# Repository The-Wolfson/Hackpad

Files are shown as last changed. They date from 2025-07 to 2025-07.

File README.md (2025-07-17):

# MIDI (Pro) Pad
A hackpad built for [Hacklub's YSWS](hackpad.hackclub.com) that sends MIDI Control Messages to your DAW of choice. It features 2 rotary encoders, 9 switches, and 16 addressable LEDs.

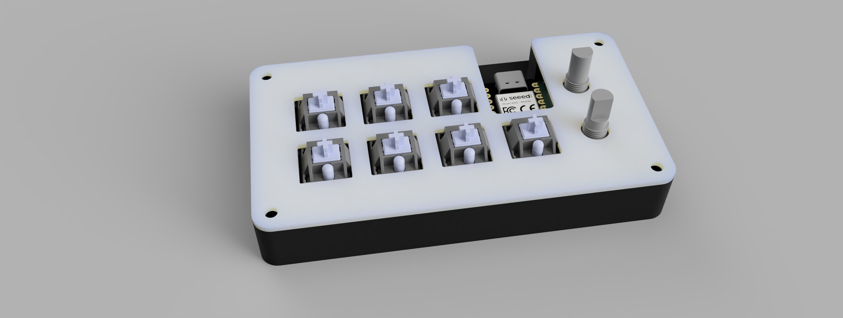
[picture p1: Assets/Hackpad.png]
Assembled

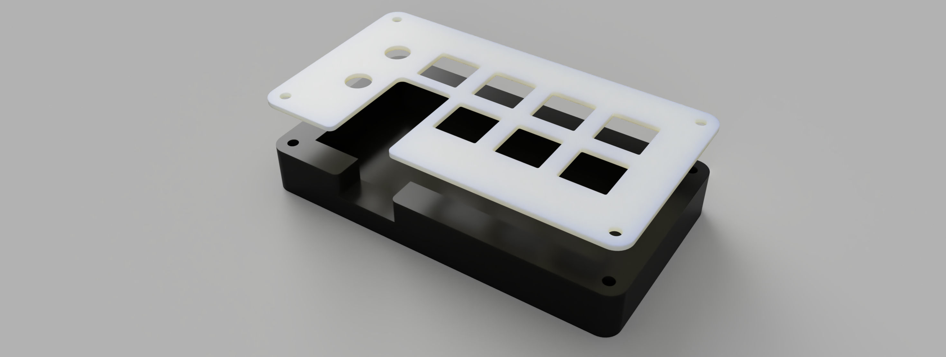
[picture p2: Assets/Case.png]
Case

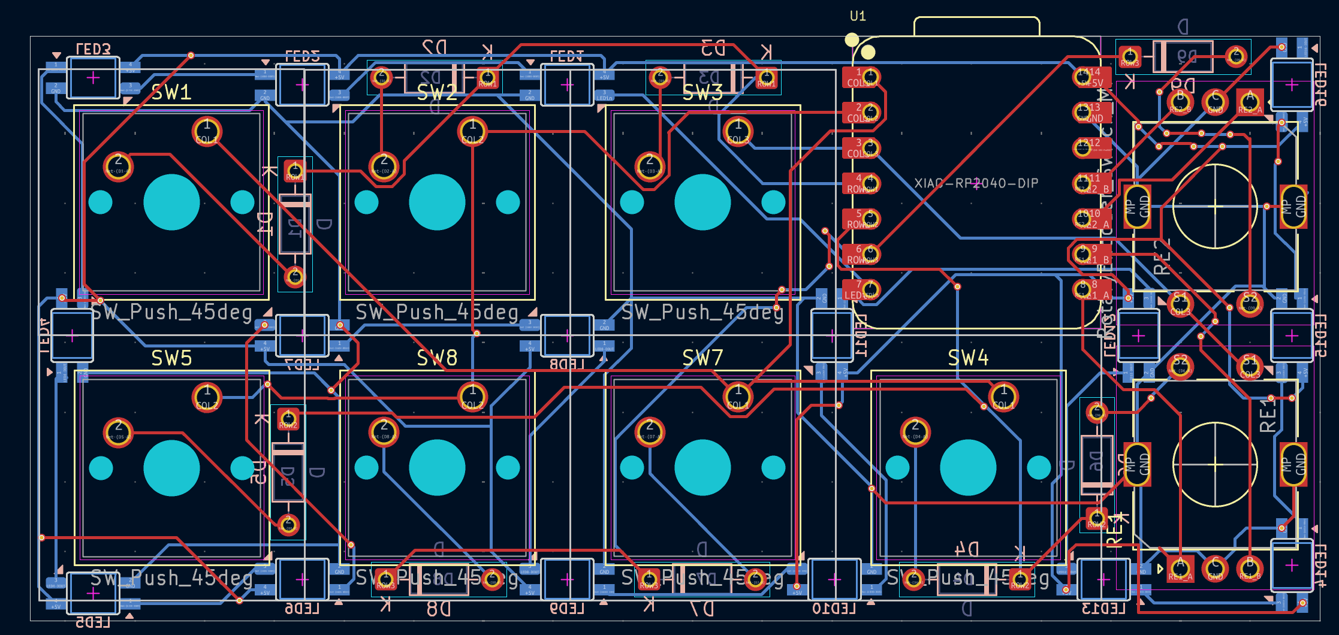
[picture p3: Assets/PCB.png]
PCB

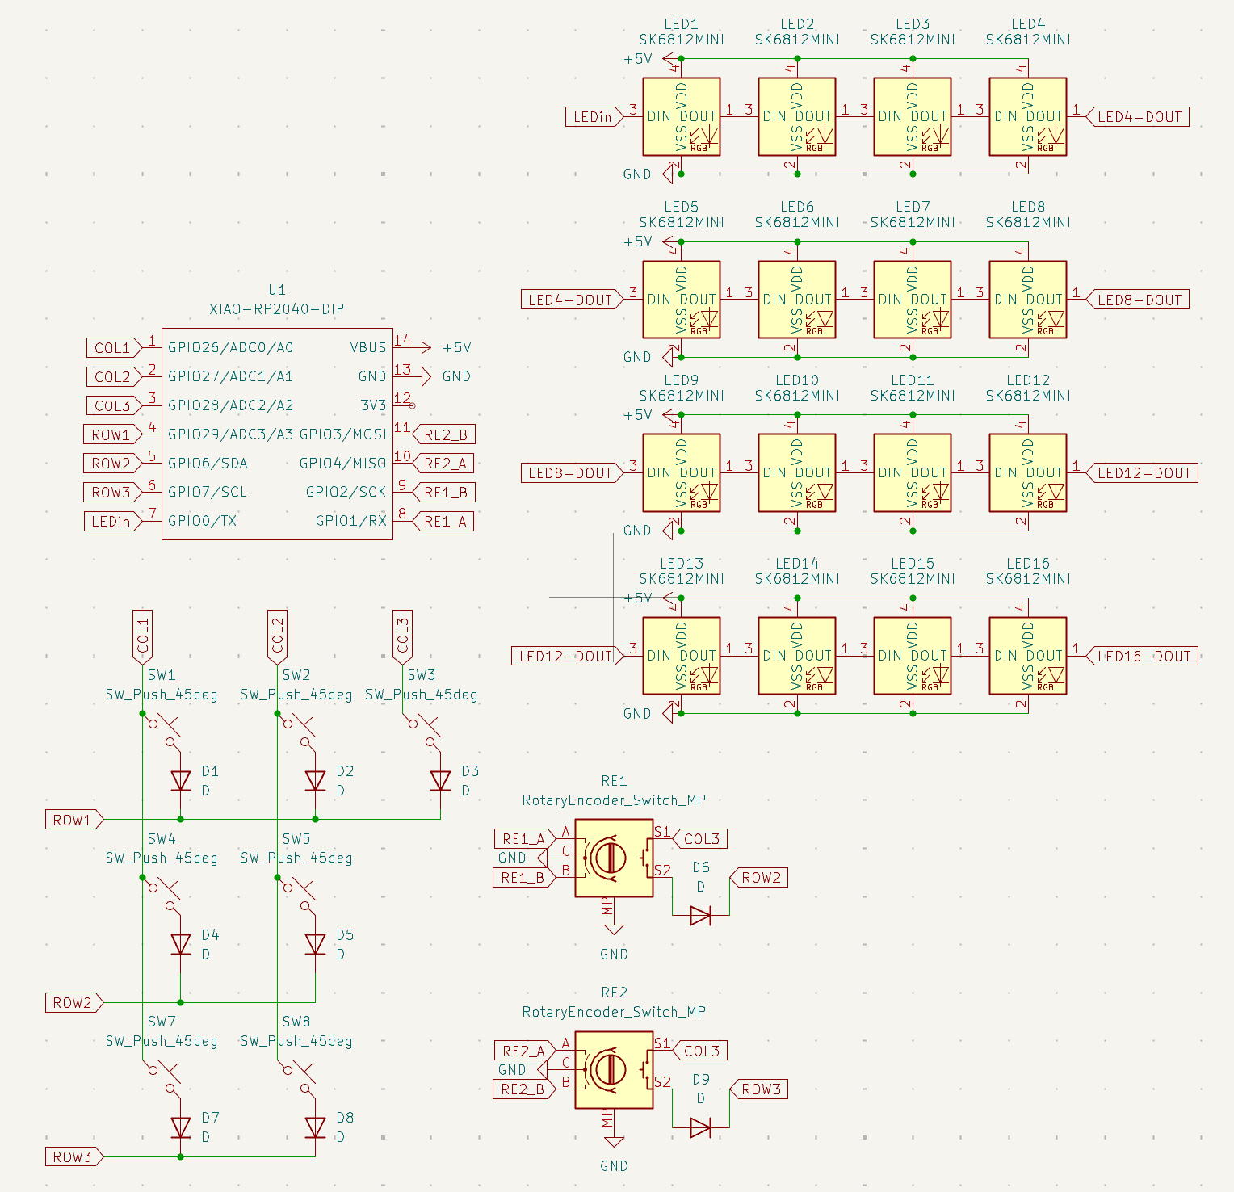
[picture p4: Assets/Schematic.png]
Schematic


## BOM
| Part | Quantity |
| - | - |
| XIAO RP2040 | 1 |
| EC11 Rotary Encoder | 2 |
| SK6812 MINI-E | 16 |
| MX-Style Switch | 7|
| Through-hole 1N4148 Diode | 9 |
| M3x16mm Screw | 4 |
| M3x5mx4mm Heatset Insert | 4 |

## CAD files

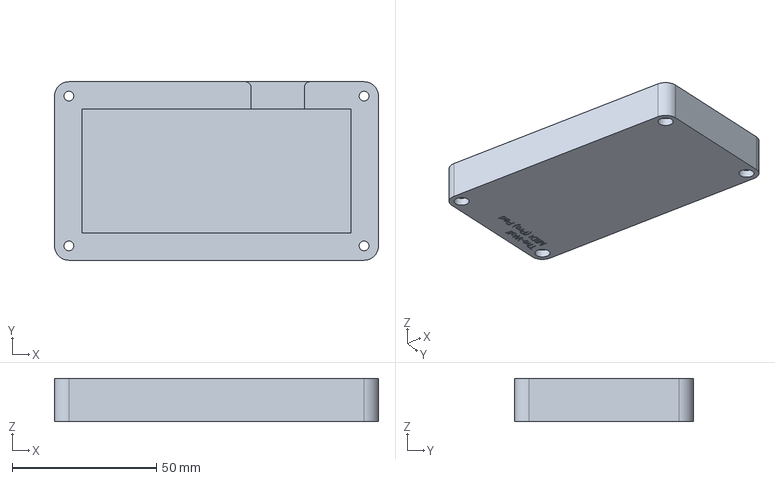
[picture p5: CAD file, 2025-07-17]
Production/Bottom.step
112.5 x 62.0 x 15.0 mm

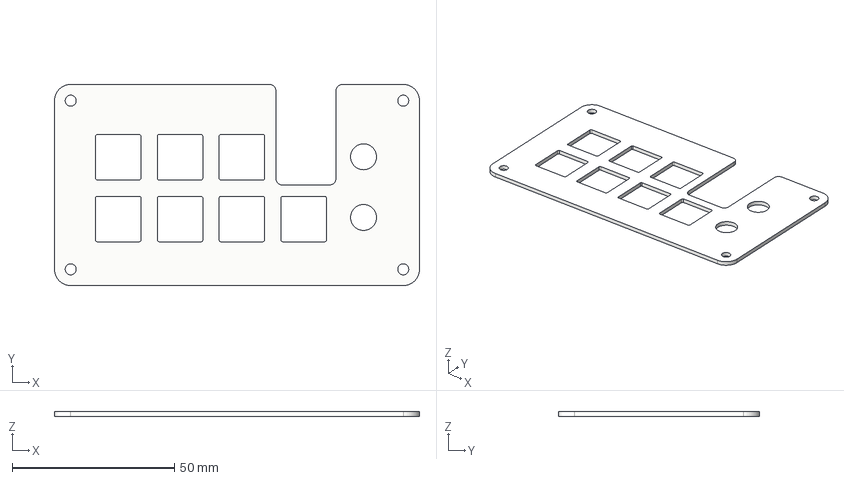
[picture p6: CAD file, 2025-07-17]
Production/Top.step
112.5 x 62.0 x 1.50 mm

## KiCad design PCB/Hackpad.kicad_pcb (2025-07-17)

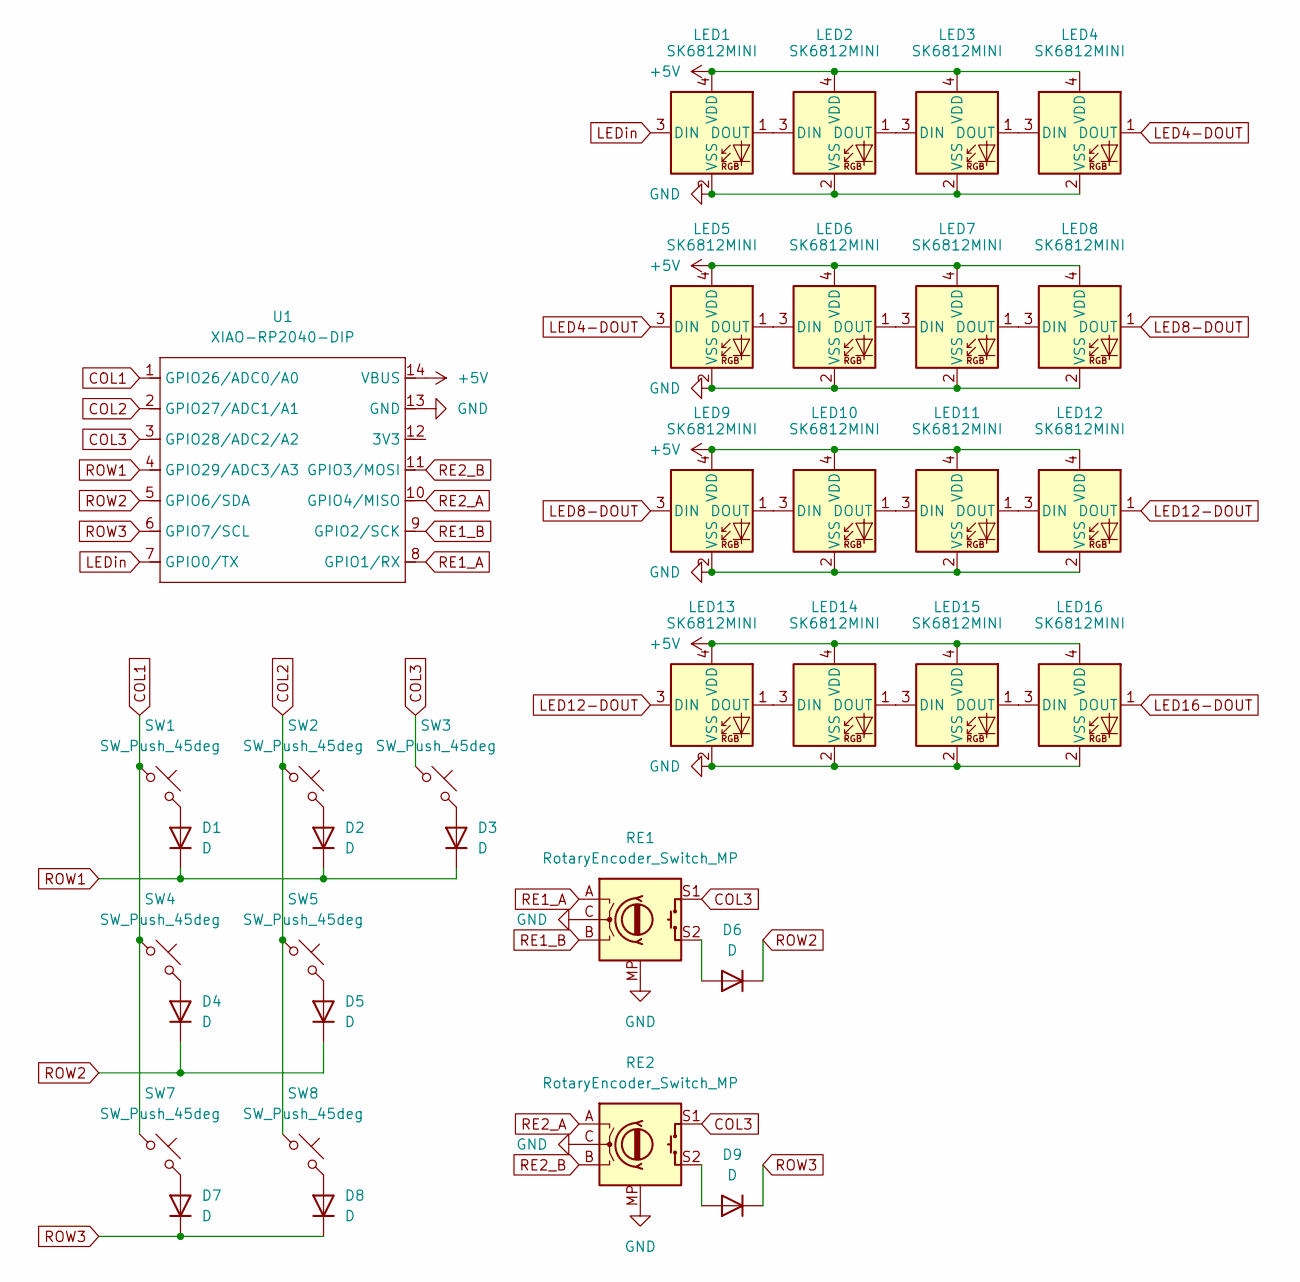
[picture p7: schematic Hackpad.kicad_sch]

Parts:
D1, D2, D3, D4, D5, D6, D7, D8, D9: D; D_DO-35_SOD27_P7.62mm_Horizontal
LED1, LED2, LED3, LED4, LED5, LED6, LED7, LED8, LED9, LED10, LED11, LED12, LED13, LED14, LED15, LED16: SK6812MINI; SK6812-MINI-E
RE1, RE2: RotaryEncoder_Switch_MP; RotaryEncoder_Alps_EC11E-Switch_Vertical_H20mm
SW1, SW2, SW3, SW4, SW5, SW7, SW8: SW_Push_45deg; SW_Cherry_MX_1.00u_PCB
U1: XIAO-RP2040-DIP

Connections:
+5V: LED1.4 (VDD), LED2.4 (VDD), LED3.4 (VDD), LED4.4 (VDD), LED5.4 (VDD), LED6.4 (VDD), LED7.4 (VDD), LED8.4 (VDD), LED9.4 (VDD), LED10.4 (VDD), LED11.4 (VDD), LED12.4 (VDD), LED13.4 (VDD), LED14.4 (VDD), LED15.4 (VDD), LED16.4 (VDD), U1.14 (VBUS)
COL1: SW1.1, SW4.1, SW7.1, U1.1 (GPIO26/ADC0/A0)
COL2: SW2.1, SW5.1, SW8.1, U1.2 (GPIO27/ADC1/A1)
COL3: RE1.S1, RE2.S1, SW3.1, U1.3 (GPIO28/ADC2/A2)
GND: LED1.2 (VSS), LED2.2 (VSS), LED3.2 (VSS), LED4.2 (VSS), LED5.2 (VSS), LED6.2 (VSS), LED7.2 (VSS), LED8.2 (VSS), LED9.2 (VSS), LED10.2 (VSS), LED11.2 (VSS), LED12.2 (VSS), LED13.2 (VSS), LED14.2 (VSS), LED15.2 (VSS), LED16.2 (VSS), RE1.C, RE1.MP, RE2.C, RE2.MP, U1.13 (GND)
LED4-DOUT: LED4.1 (DOUT), LED5.3 (DIN)
LED8-DOUT: LED8.1 (DOUT), LED9.3 (DIN)
LED12-DOUT: LED12.1 (DOUT), LED13.3 (DIN)
LED16-DOUT: LED16.1 (DOUT)
LEDin: LED1.3 (DIN), U1.7 (GPIO0/TX)
unnamed: D1.2 (A), SW1.2
unnamed: D2.2 (A), SW2.2
unnamed: D3.2 (A), SW3.2
unnamed: D4.2 (A), SW4.2
unnamed: D5.2 (A), SW5.2
unnamed: D6.2 (A), RE1.S2
unnamed: D7.2 (A), SW7.2
unnamed: D8.2 (A), SW8.2
unnamed: D9.2 (A), RE2.S2
unnamed: LED1.1 (DOUT), LED2.3 (DIN)
unnamed: LED2.1 (DOUT), LED3.3 (DIN)
unnamed: LED3.1 (DOUT), LED4.3 (DIN)
unnamed: LED5.1 (DOUT), LED6.3 (DIN)
unnamed: LED6.1 (DOUT), LED7.3 (DIN)
unnamed: LED7.1 (DOUT), LED8.3 (DIN)
unnamed: LED9.1 (DOUT), LED10.3 (DIN)
unnamed: LED10.1 (DOUT), LED11.3 (DIN)
unnamed: LED11.1 (DOUT), LED12.3 (DIN)
unnamed: LED13.1 (DOUT), LED14.3 (DIN)
unnamed: LED14.1 (DOUT), LED15.3 (DIN)
unnamed: LED15.1 (DOUT), LED16.3 (DIN)
RE1_A: RE1.A, U1.8 (GPIO1/RX)
RE1_B: RE1.B, U1.9 (GPIO2/SCK)
RE2_A: RE2.A, U1.10 (GPIO4/MISO)
RE2_B: RE2.B, U1.11 (GPIO3/MOSI)
ROW1: D1.1 (K), D2.1 (K), D3.1 (K), U1.4 (GPIO29/ADC3/A3)
ROW2: D4.1 (K), D5.1 (K), D6.1 (K), U1.5 (GPIO6/SDA)
ROW3: D7.1 (K), D8.1 (K), D9.1 (K), U1.6 (GPIO7/SCL)

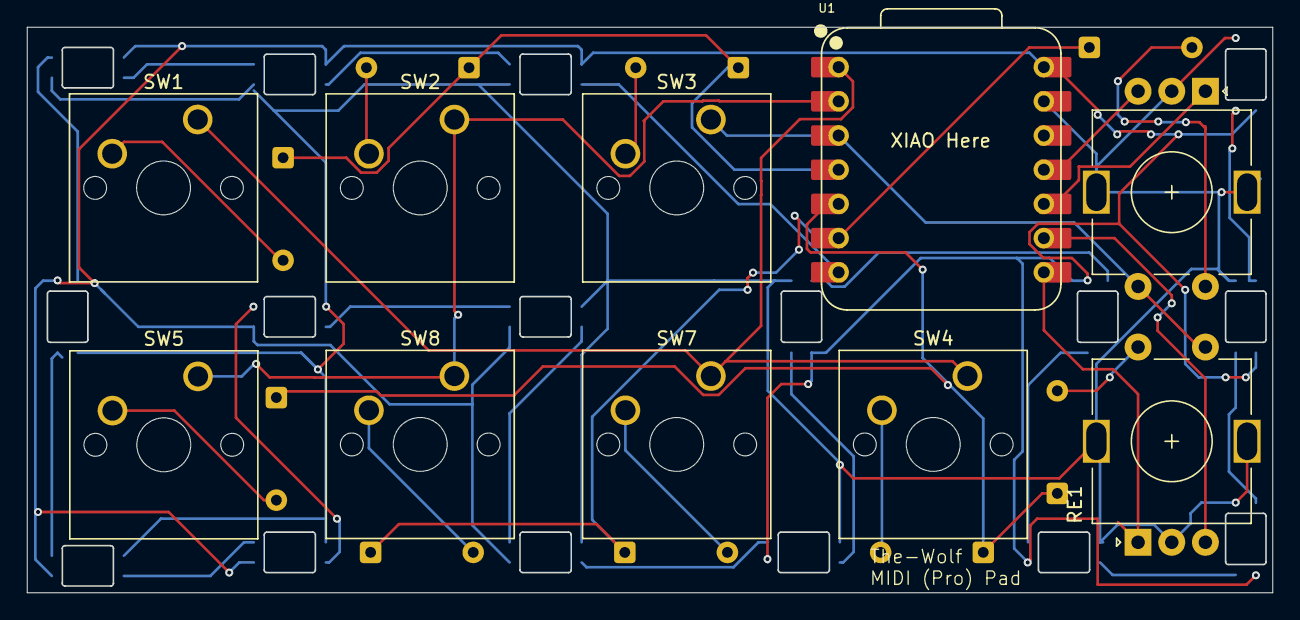
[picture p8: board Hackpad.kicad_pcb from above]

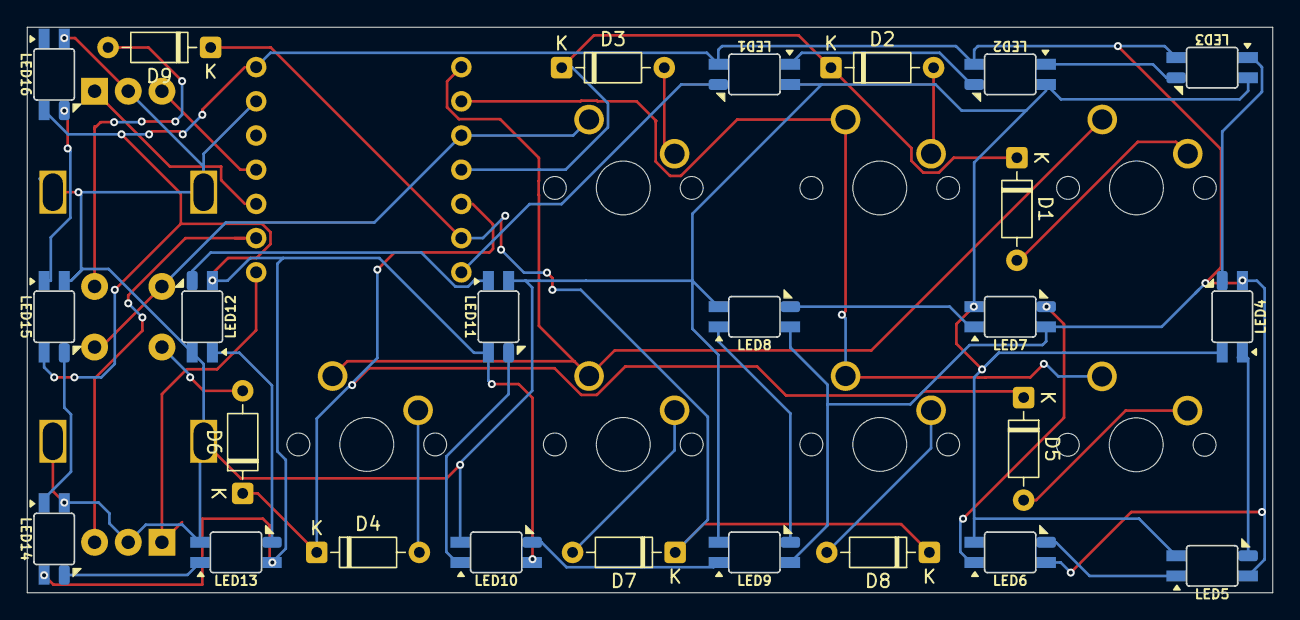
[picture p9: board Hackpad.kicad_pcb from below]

Board: 2 copper layers, 92.5 x 42.0 mm, 35 parts (25 on the bottom side), 37 nets.

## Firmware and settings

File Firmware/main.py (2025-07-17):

import board

#Rotary 1 A - GP1
#Rotary 1 B - GP2
#Rotary 2 A - GP4
#Rotary 2 B - GP3

#Led Strip - GP0
#Column 1 = GP26
#Column 2 = GP27
#Column 3 = GP28
#Row 1 = GP29
#Row 2 = GP6
#Row 3 = GP7

from kmk.kmk_keyboard import KMKKeyboard
from kmk.keys import KC
from kmk.modules.encoder import EncoderHandler
from kmk.modules.midi import MidiKeys, MIDI_CC
from kmk.modules.keypad import MatrixScanner
from kmk.extensions.RGB import RGB

keyboard = KMKKeyboard()

encoder_handler = EncoderHandler()
keyboard.modules.append(encoder_handler)

midi_keys = MidiKeys()
keyboard.modules.append(midi_keys)

rgb = RGB(pixel_pin=board.GP0, num_pixels=16)
keyboard.extensions.append(rgb)

keyboard.matrix = MatrixScanner(
    cols=(board.GP26, board.GP27, board.GP28),
    rows=(board.GP29, board.GP6, board.GP7)
)

encoder_handler.pins = (
    (board.GP1, board.GP2),
    (board.GP4, board.GP3),
)

encoder_handler.map = [
    ((MIDI_CC, 0x1A, 1), (MIDI_CC, 0x1A, 127)),
    ((MIDI_CC, 0x2A, 1), (MIDI_CC, 0x2A, 127)),
]

keyboard.keymap = [
    [
        KC.MIDI_CC(0x3A),
        KC.MIDI_CC(0x3B),
        KC.MIDI_CC(0x3C),
        KC.MIDI_CC(0x4A),
        KC.MIDI_CC(0x4B),
        KC.MIDI_CC(0x4C),
        KC.MIDI_CC(0x5A),
        KC.MIDI_CC(0x5B),
        KC.MIDI_CC(0x5C),
    ]
]


if __name__ == '__main__':
    keyboard.go()
